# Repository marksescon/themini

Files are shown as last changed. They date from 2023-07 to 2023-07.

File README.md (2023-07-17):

# themini
Mini OD/Fuzz files

Disclaimer: Please double-check my work to ensure this circuit will work. I have built the pedal. It works. However, I cannot guarantee a fully functioning pedal and/or promise that the PCB is error-free. Proceed with caution. I am not responsible for any harm or injury that may arise from building this pedal. I have no association with the original builder/designer of the Mini. Product names are for comparison purposes only. For assistance troubleshooting, please refer to the multitude of online forums available like r/diypedals on Reddit.

Update - 07/172023

These are the files for fabricating a SSBS Mini clone through any services like JLCPCB or PCBWay.

General Documents:
- MINIPCB_BuildInstructions - build of materials, instructions for building including advice for a successful build
- SSBSMINISCHEMATIC.png - picture of the schematic

Files for any PCB design program like Eagle or KiCAD:
- SSBSMINI-THROUGHHOLE.brd - PCB for PCB CAD program
- SSBSMINI-THROUGHHOLE.sch - Schematic for PCB CAD program
- SSBSMini-PCBtraces.png - picture of the traces on the board

Alternatively, here is a link for an OshPark board: https://oshpark.com/shared_projects/tuJtiGCm.

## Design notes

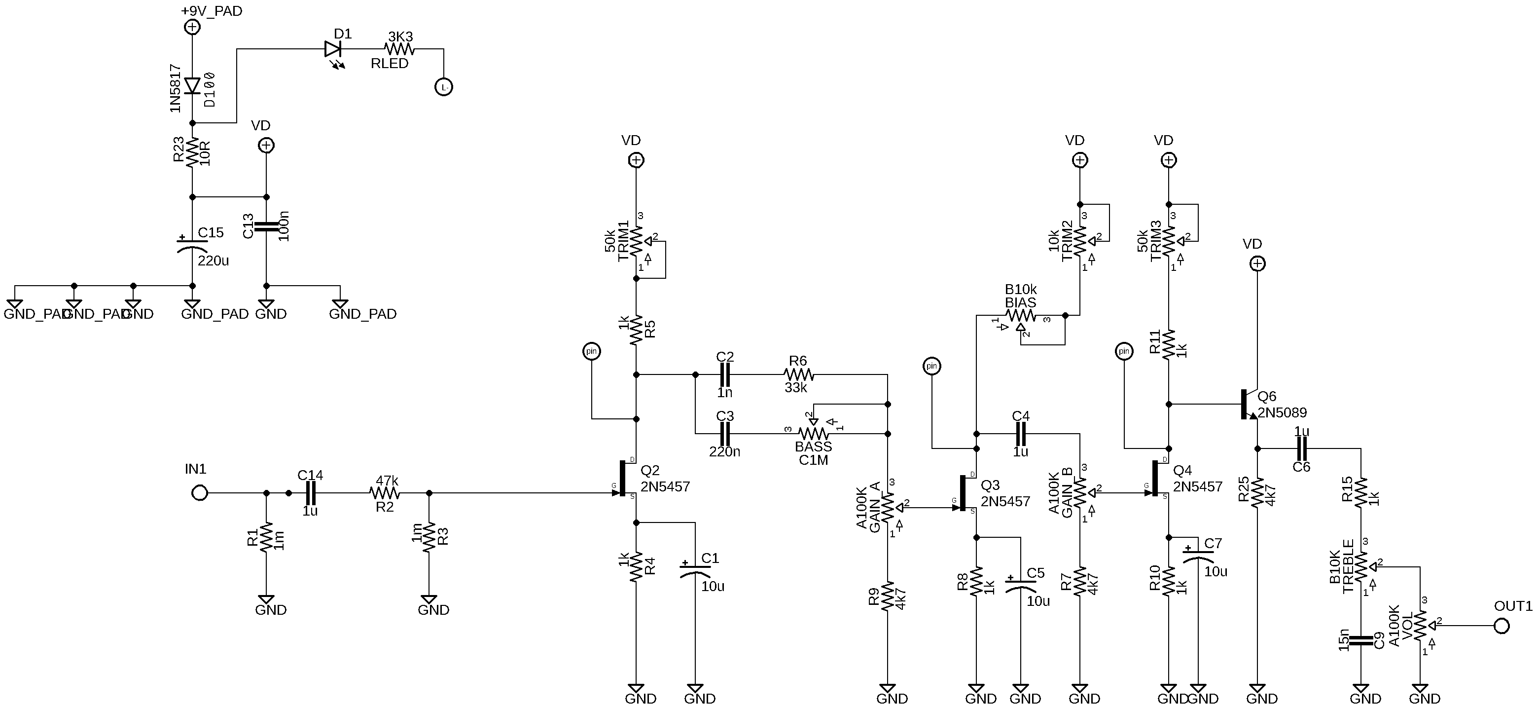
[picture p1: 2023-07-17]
SSBSMINISCHEMATIC.png

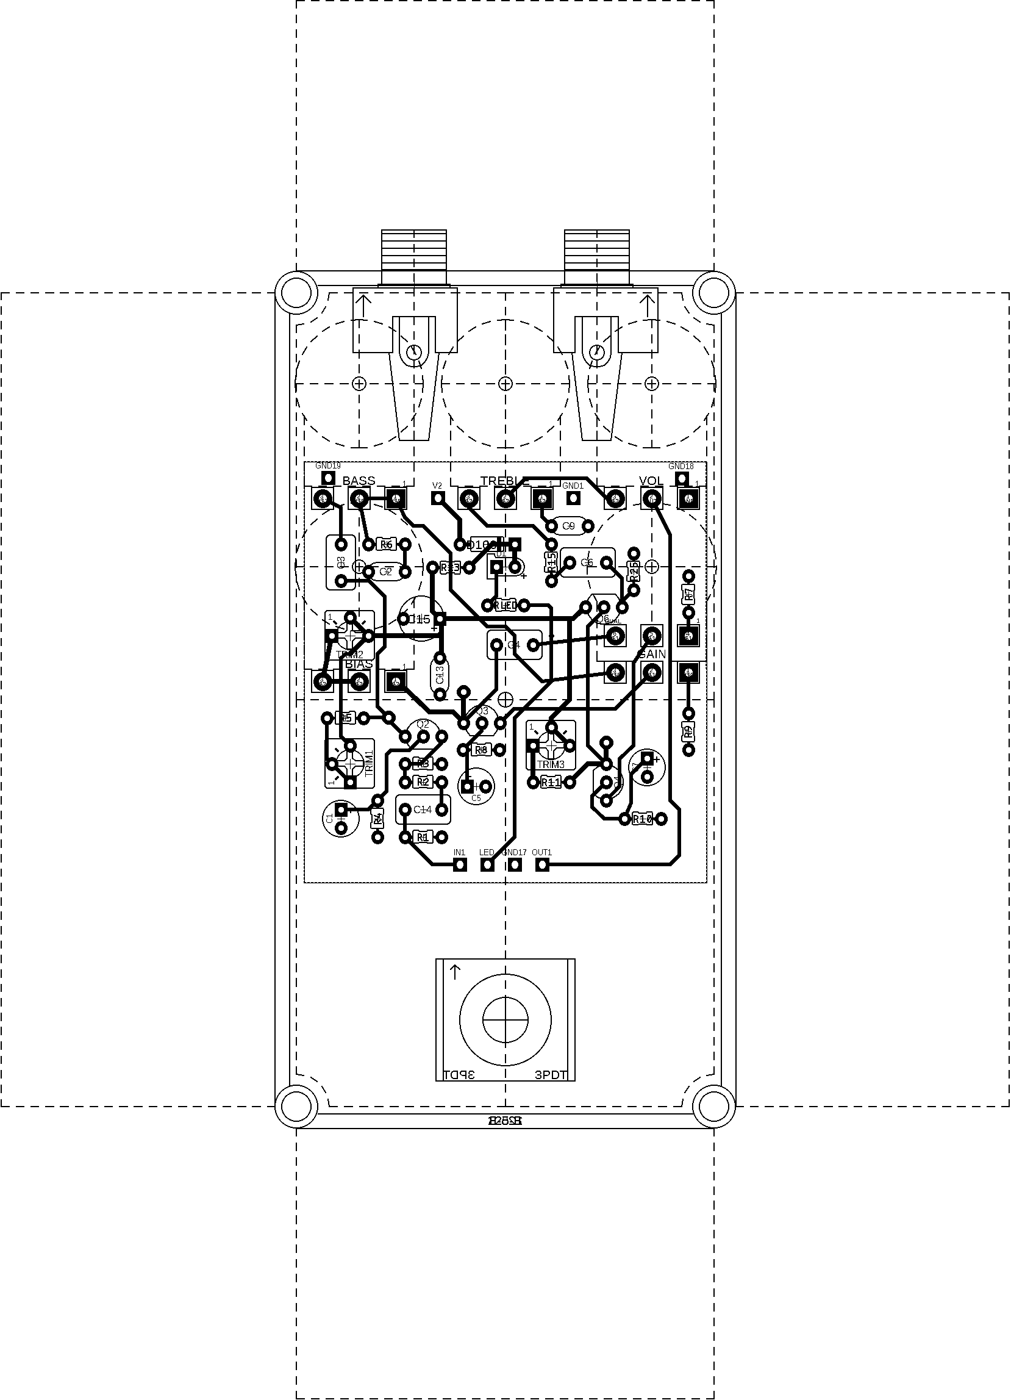
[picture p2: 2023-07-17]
SSBSMini-PCBtraces.png

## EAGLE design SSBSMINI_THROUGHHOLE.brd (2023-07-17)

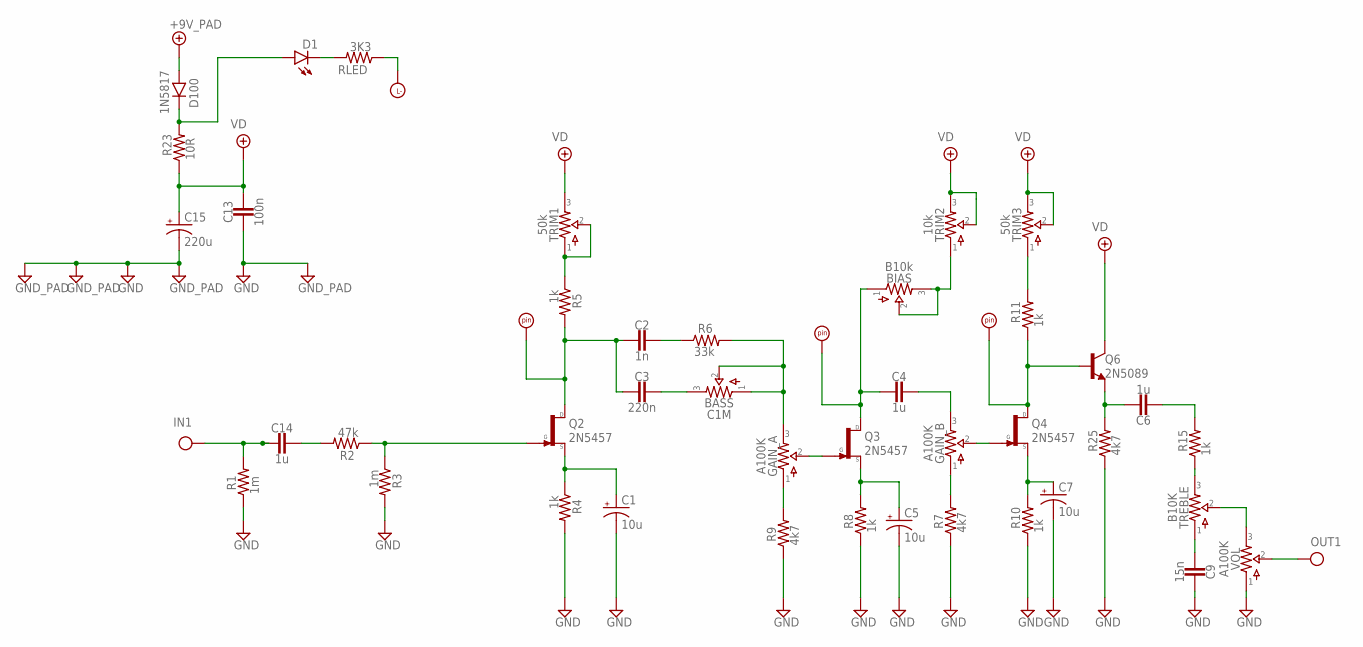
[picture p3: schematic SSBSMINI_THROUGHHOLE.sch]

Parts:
BASS: C1M; 16MM_B.MOUNT
BIAS: B10k; 16MM_B.MOUNT
C1, C5, C7: 10u; 050_020_1
C2: 1n; 0.2".SML
C3: 220n; 0.2".MED
C4, C6, C14: 1u; 0.2".MED
C9: 15n; 0.2".SML
C13: 100n; 0.2".SML
C15: 220u; 063_025_2
D1: LED3MM
D100: 1N5817; DO35-3
GAIN: A100K; 16MM_DUALGANG
GND1, GND17, GND18, GND19: GND_PAD; SQUARE
IN1: IN; SQUARE
LED: LED-; SQUARE
OUT1: OUT; SQUARE
Q2, Q3, Q4: 2N5457; TO92
Q6: 2N5089; TO92
R1, R3: 1m; R0204/2
R2: 47k; R0204/2
R4, R5, R8, R10, R11, R15: 1k; R0204/2
R6: 33k; R0204/2
R7, R9, R25: 4k7; R0204/2
R23: 10R; R0204/2
RLED: 3K3; R0204/2
TREBLE: B10K; 16MM_B.MOUNT
TRIM1, TRIM3: 50k; TRIM1
TRIM2: 10k; TRIM1
U$5, U$6, U$7: PADS.RND_NL; PAD2
V2: +9V_PAD; SQUARE
VOL: A100K; 16MM_B.MOUNT

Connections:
+9V: D100.A, V2.1
GND: C1.-, C5.-, C7.-, C9.1, C13.2, C15.-, GND1.1, GND17.1, GND18.1, GND19.1, R1.1, R3.2, R4.2, R7.1, R8.1, R9.1, R10.1, R25.1, VOL.1
IN: C14.2, IN1.1, R1.2
unnamed: R5.1, TRIM1.1, TRIM1.2
unnamed: C14.1, R2.2
unnamed: Q2.3 (G), R2.1, R3.1
unnamed: C1.+, Q2.2 (S), R4.1
unnamed: C2.2, C3.2, Q2.1 (D), R5.2, U$5.P$1
unnamed: C2.1, R6.1
unnamed: BASS.3, C3.1
unnamed: BASS.1, BASS.2, GAIN.3, R6.2
unnamed: GAIN.1, R9.2
unnamed: D1.A, D100.C, R23.2
unnamed: GAIN.2, Q3.3 (G)
unnamed: C5.+, Q3.2 (S), R8.2
unnamed: D1.K (C), RLED.2
unnamed: C4.1, GAIN.6 (3)
unnamed: GAIN.4 (1), R7.2
unnamed: C7.+, Q4.2 (S), R10.2
unnamed: Q4.1 (D), Q6.2 (B), R11.1, U$7.P$1
unnamed: GAIN.5 (2), Q4.3 (G)
unnamed: C6.1, Q6.3 (E), R25.2
unnamed: C6.2, R15.2
unnamed: R15.1, TREBLE.3
unnamed: C9.2, TREBLE.1
unnamed: TREBLE.2, VOL.3
unnamed: LED.1, RLED.1
unnamed: BIAS.2, BIAS.3, TRIM2.1
unnamed: BIAS.1, C4.2, Q3.1 (D), U$6.P$1
unnamed: R11.2, TRIM3.1
OUT: OUT1.1, VOL.2
VD: C13.1, C15.+, Q6.1 (C), R23.1, TRIM1.3, TRIM2.2, TRIM2.3, TRIM3.2, TRIM3.3

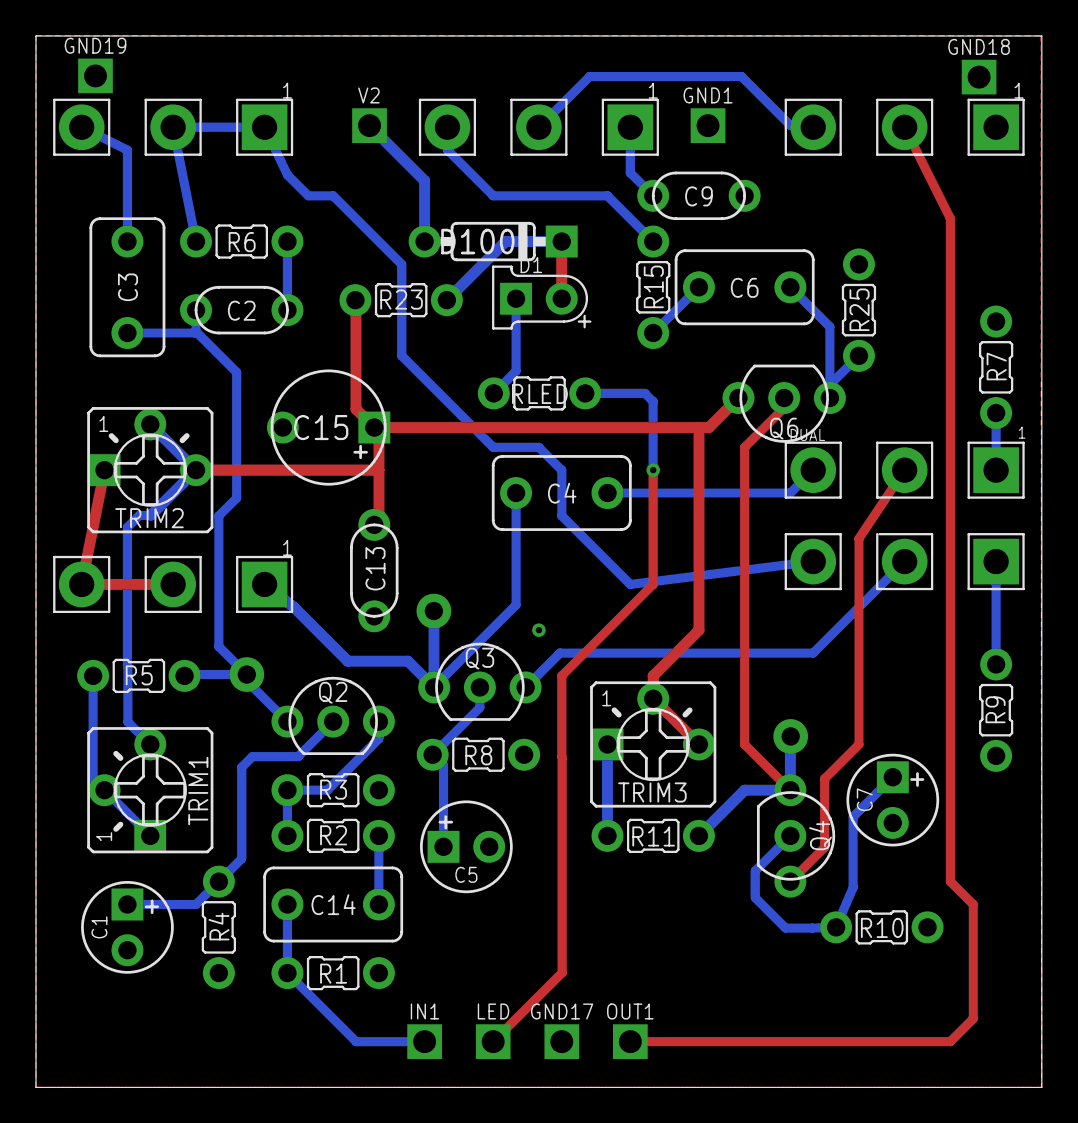
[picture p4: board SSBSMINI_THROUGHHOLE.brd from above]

Board: 2 copper layers, 55.9 x 58.4 mm, 54 parts (1 on the bottom side), 32 nets.

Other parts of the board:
U$2: 3PDT
U$3, U$4: LUMBURG_TOP

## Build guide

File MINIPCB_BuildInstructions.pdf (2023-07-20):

# MINI (CLONE) PCB

### LAST UPDATE: July 19, 2023

DISCLAIMER: I am not responsible for any harm or injury or even fatality that may arise from the building and usage of this device/PCB.

## BUILD OF MATERIALS

Capacitors

C1 | 10u
C2 | 1n
C3 | 220n
C4 | 1u
C5 | 10u
C6 | 1u
C7 | 10u
C9 | 15n
C13 | 100n
C14 | 1u
C15 | 220u

Diodes

D1 | LED
D100 | 1N5817

Semiconductors

Q2 | J201
Q3 | 2N5457
Q4 | J201
Q6 | 2N5089

Resistors

R1 | 1m
R2 | 47k
R3 | 1m
R4 | 1k
R5 | 1k
R6 | 33k
R7 | 4k7
R8 | 1k
R9 | 4k7
R10 | 1k
R11 | 1k
R15 | 1k
R23 | 10R
R25 | 4k7
RLED | 3K3

Potentiometers

TREBLE B10K
GAIN | B100K (dual gang)
VOL | A100K
BASS | C1M
BIAS | B10K

TRIM1 50k
TRIM2 10-20k
TRIM3 50k

## Notes:

- JFETS
- Knowledge of biasing and/or selecting JFETs is HIGHLY RECOMMENDED and use of SMT JFETs is HIGHLY RECOMMENDED.
- Depending on what JFETs are used (model, specs, etc.), you may need to alter the source resistor (Rs). I
recommend socketing R4, R8, and R10. From my own experience, biasing Q3 and finding the appropriate source resistor (R8) is imperative to gain the full potential of the Bias knob.
- There is a difference in the schematic JFETs and BOM due to the variance in reports about these parts. For example, in Gray Bench’s analysis of the pedal, he identified the pedal had three 2N5457 JFETs for Q2, Q3, Q4. In some schematics like Effects Layouts’ Liliput, Q2 and Q4 are J201 and Q3 is 2N5457. My builds match the similar JFET choice of Effects Layouts. Furthermore, if you use 2N5457, you will need R4, R8, and R10 accordingly because of the variance in Rs.
- Trimmers
- Different schematics contain varying values for the trimmers. I personally use 50K in all my builds.
- Bias Knob
- Preface that there is a Bias knob and there is the action of biasing a JFET’s drain voltage.
- To adjust Q3, the gain stage associated with the Bias knob, set the Bias to noon (50% wiper). Use TRIM2 to bias the drain voltage of Q3 to 4.5V. When turning the Bias knob, your drain voltage should change between 2 to 7V. If the knob does not work, you can either try to adjust the source resistor (make it higher or even lower).
- If this does not work, you may need to try out another JFET from your supply pile. In my experience (anecdotal), one out of ten of my 2N5457s will not react correctly to the Bias knob.

- Pot Selection
- For Gain, B100K dual-gang potentiometer was noted in the initial schematic posted on an online forum and corroborated by the initial creator himself. However, Gray Bench noted it is an A100K dual-gang potentiometer in his analyzed model.
- For Bass, C500K was noted in the initial schematic posted on an online forum and corroborated by the initial creator himself. However, Gray Bench noted it is a C1M potentiometer in his analyzed model.

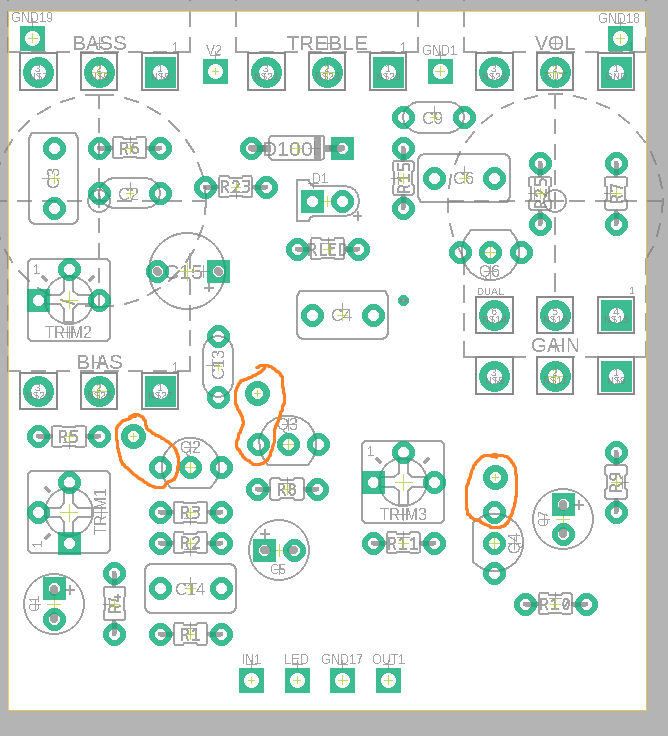
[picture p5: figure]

### Bias all the drain voltages as follows: - Q2 = 5.1 V +/- 0.2V - Q3 = 4.5 V (adjust while Bias knob is 0:00)

- Q4 = 4.5-4.7V

### (I personally do 4.5V for all of these.)

You can use the empty pads to place a multimeter probe. The circles show which respective drain pin applies to each empty pad.

### Schematic

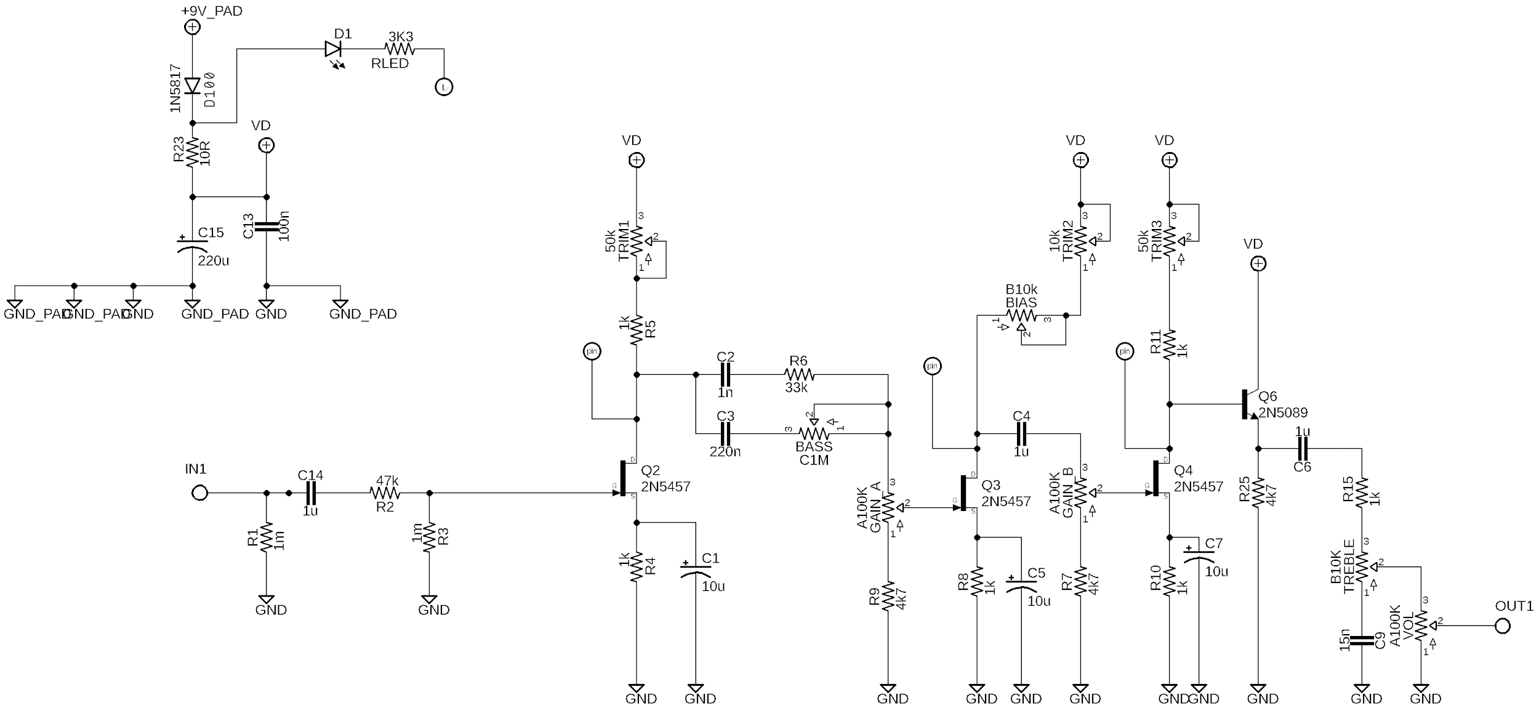
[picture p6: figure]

### Wiring Diagram

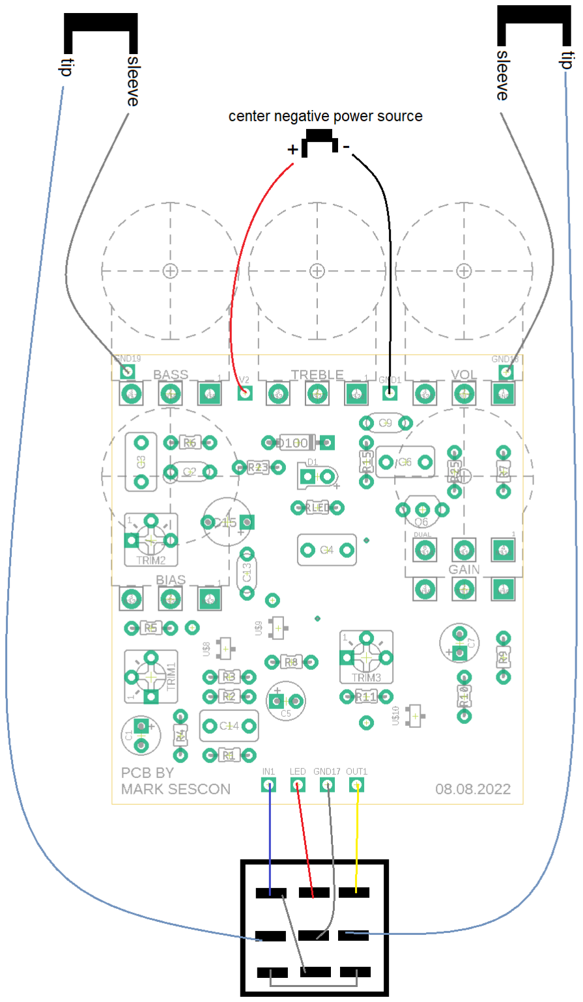
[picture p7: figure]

### Proposed Drilling Template

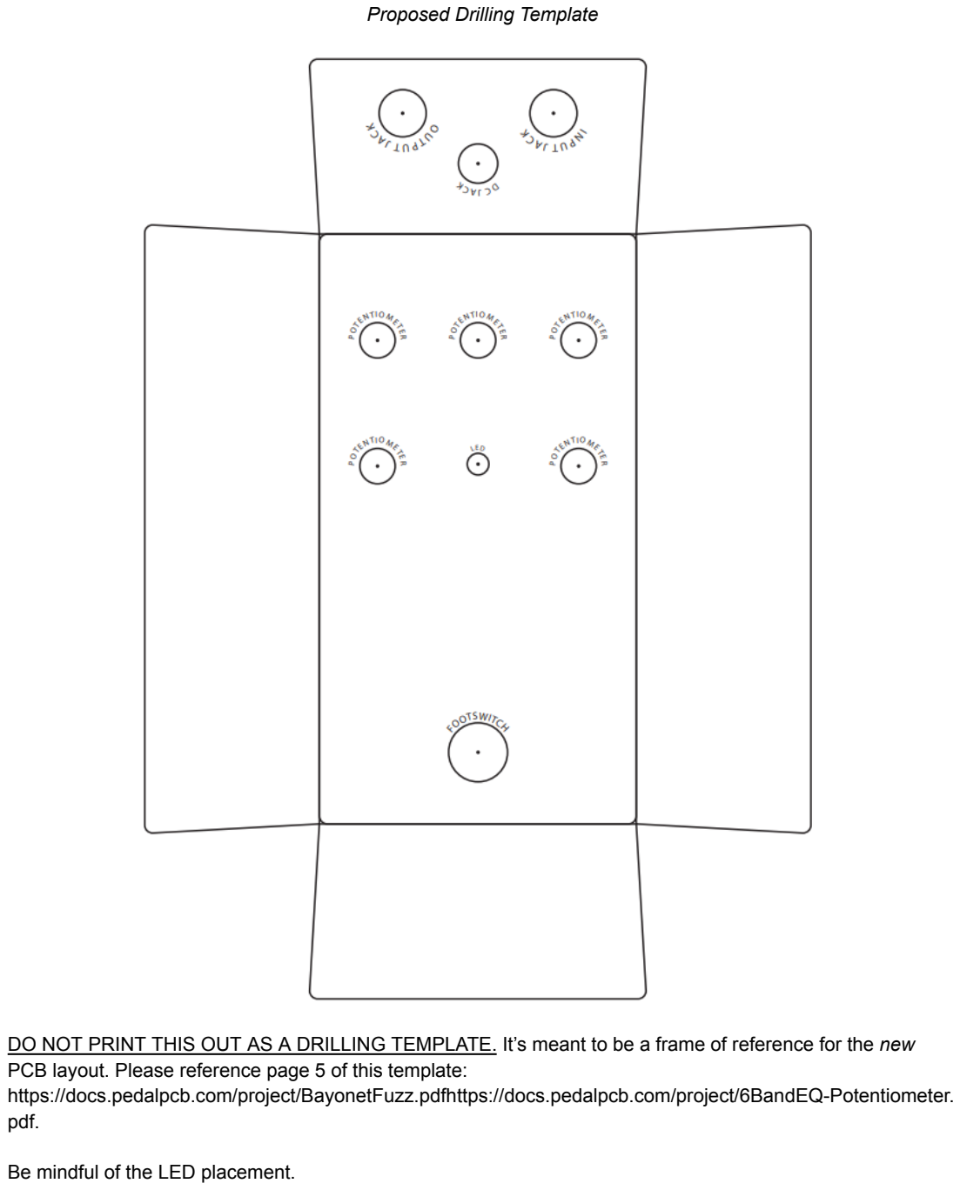
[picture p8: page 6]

DO NOT PRINT THIS OUT AS A DRILLING TEMPLATE. It’s meant to be a frame of reference for the new

### PCB layout. Please reference page 5 of this template:

https://docs.pedalpcb.com/project/BayonetFuzz.pdfhttps://docs.pedalpcb.com/project/6BandEQ-Potentiometer. pdf.

Be mindful of the LED placement.

### Additional Reading: - Adjusting trimmer of Q3 in light of Bias and the source resistor (R8): https://www.freestompboxes.org/viewtopic.php?t=30921

- Biasing JFETs: http://diy.smallbearelec.com/HowTos/BreadboardBareAss/BreadboardBareAss.htm

### - Brian commenting with insight: http://tagboardeffects.blogspot.com/2016/07/smallsoundbigsound-mini-overdrive.html - Run Off Groove insight on JFETs: http://www.runoffgroove.com/fetzervalve.html

### Release Notes

- 2022
- August 15 - Initial draft.
- August 21 - Additional instructions about biasing JFETs. Additional instructions about Gain pot selection.

### - August 29 - Additional information about JFET and potentiometer selection. Additional

information about how to adjust Bias knob. Wiring diagram.
- 2023
- May 10 - I have since updated the PCB to accommodate the six knob configuration on Tayda

### and PedalPCB. No changes to the schematic have been made but some traces have been

redone to accommodate this new layout. Included in this BOM is a proposed drill template that

### references page 5 of this template:

https://docs.pedalpcb.com/project/BayonetFuzz.pdfhttps://docs.pedalpcb.com/project/6BandEQ-Potentiometer.pdf. (https://docs.pedalpcb.com/project/BayonetFuzz.pdfhttps://docs.pedalpcb.com/project/6BandEQ-Potentiometer.pdf) Be mindful of the LED placement.
■ Background: The original PCB is meant to fit in the six knob configuration as proposed by Tayda and PedalPCB. Unfortunately, the spacing of the potentiometers was NOT correct. The original PCB will fit into the six knob configuration on Tayda and PedalPCB but will require the potentiometer legs be bent slightly (0.05 millions of an inch).
- July - Updated schematic picture and provided additional information about adjusting the drain voltage for Q3. I have come to find that many people are having issues with the Bias knob “not working,” but the solution is quite straightforward albeit does require some cognizance on behalf of the builder.
